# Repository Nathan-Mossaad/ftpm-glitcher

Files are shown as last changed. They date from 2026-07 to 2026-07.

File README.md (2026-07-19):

# Glitching firmware for the AMD SP

(currently only tested on a A520M-HVS & AMD Ryzen 3600)

# Contents

- [Wiring setup](#wiring-setup)
- [Parameter Determination](#parameter-determination)
- [Docs](#docs)
- [Building](#building)
  - [Pico firmware](#pico-firmware)
  - [Cli tool](#cli-tool)
  - [Helper scripts](#helper-scripts)
- [Tips & Tricks](#tips--tricks)

# Wiring setup

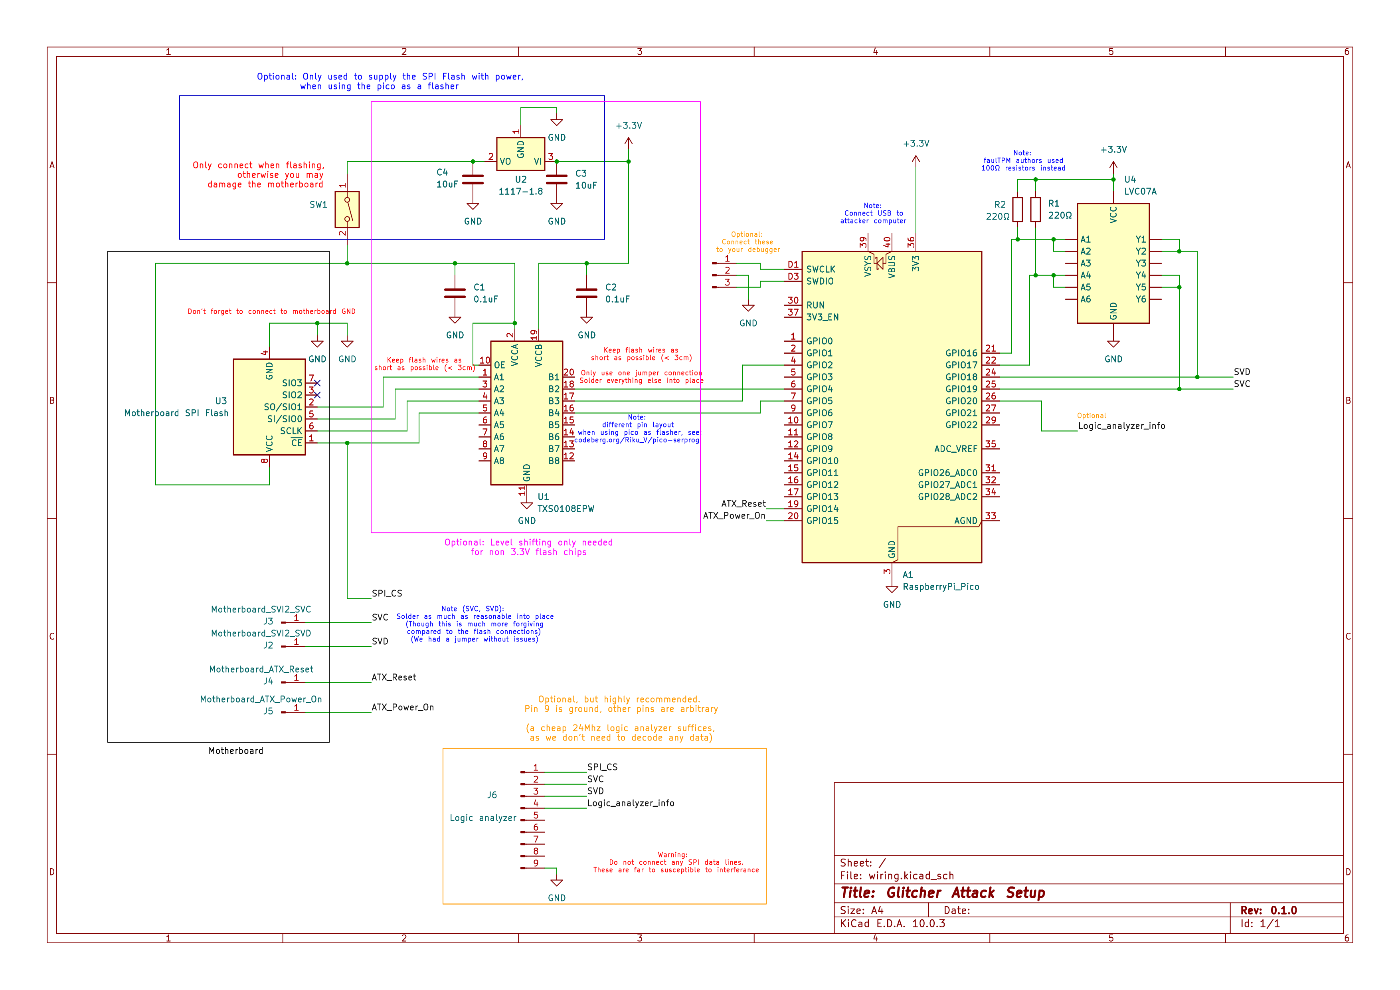
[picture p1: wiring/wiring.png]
wiring png


As pdf: [wiring pdf](./wiring/wiring.pdf)

# Parameter Determination

For the following I'd recommend you read both "faultpm: Exposing amd ftpms' deepest secrets" and "One glitch to rule them all: Fault injection attacks against amd's secure encrypted virtualization"

Use instructions from upstream: [parameter determination by PSPReverse](https://github.com/PSPReverse/amd-sp-glitch/blob/main/attack-code/ParameterDetermination.md)

I would recommend slight some slight variations:

1. Backup the SPI flash (important, as the ftpm secrets are stored there) e.g. using [pico-serprog](https://codeberg.org/Riku_V/pico-serprog)
2. Prepare the modified firmware:

- e.g. [hello world](https://github.com/PSPReverse/amd-sp-glitch/tree/main/payloads/hello-world) (Note it only outputs "H" due to a bug)
- Use [psptool](https://github.com/PSPReverse/PSPTool) to patch the firmware to create a modified SPI flash image

3. Flash the modified firmware
4. Determine the chip select count till ARK validation by using `glitcher count-chip-selects --reboot` (in our case 33)
5. Flash the original firmware
6. Use a few pulses (e.g. 31), use a low wait-duration and increase `dip-duration` till the target fully crashes. The target test range should end slightly before the target crashes. Test using `glitcher attack --chip-select-count <CHIP_SELECT_COUNT> --wait-duration-ns <WAIT_DURATION_NS> --dip-duration-ns <DIP_DURATION_NS> --spi-byte-count 2`
7. Use the logic analyzer to align the end of the second SVI2 packet injection shortly before the end of the validation window. If you have no logic analyzer, you will have to compensate by increaseing the wait-duration range to definitly hit the ark validation.
8. Refine params by setting the custom ranges in [determine-params](helpers/determine-params.py) and run. Now use the resulting values with [duration_test_plot](https://github.com/Nathan-Mossaad/amd-sp-glitch/blob/5e63abd1f0da41acaa2ef0fc65212f0690687d37/attack-code/duration_test_plot.py) to determine a smaller range, in accordance with "One glitch".
9. Flash the modified firmware
10. Start glitching using [extract-data](./helpers/extract-data.py) (see section [Helper scripts](#helper-scripts) for how to use [monitor.sh](./helpers/monitor.sh))

# Docs

Mostly missing, refer to `--help` of `glitcher` for now.

# Building

> [!NOTE]
> This project is only intended for use on Linux.

Install rustup & cargo:

[https://rust-lang.org/tools/install/](https://rust-lang.org/tools/install/)

## Pico firmware

Simple setup:

```bash
# Install pico specific target
rustup target add thumbv6m-none-eabi
# compile the firmware
cd glitcher-controller
cargo build -r
# Generating the uf2
cargo install elf2uf2-rs
elf2uf2-rs target/thumbv6m-none-eabi/release/glitcher-controller target/thumbv6m-none-eabi/release/glitcher-controller.uf2
# Now you can enter bootloader mode on the pico (by holding bootsel while plugging it in) and copy the uf2 file to it.
```

With debugging support:

You can use any [probe-rs](https://probe.rs/docs/getting-started/probe-setup/) compatible debugger, e.g. a PicoProbe (a second pico): [download](https://github.com/raspberrypi/debugprobe/releases) Wiring instructions: [wiring](https://mcuoneclipse.com/2022/09/17/picoprobe-using-the-raspberry-pi-pico-as-debug-probe/)

```bash
# Install pico specific target
rustup target add thumbv6m-none-eabi
# compile the firmware
cd glitcher-controller
# This will build, flash and then attach to the debug output of the pico
cargo run -r
```

## Cli tool

> [!NOTE]
> Make sure your user account belongs to the group that grants access to USB serial devices (for example, `dialout`).

Direct compile and run

```bash
# compile the cli tool
cd glitcher-cli
cargo run -r -- --help
# Check versions on different serial port
cargo run -r -- --port /dev/ttyACM1 check-version
```

Alternatively you may wish to add `glitcher` to your path and use e.g. `glitcher generate-completions zsh` to generate completions for your shell.

## Helper scripts

Managed via [uv](https://docs.astral.sh/uv/getting-started/installation/)

> [!NOTE]
> The main project needs to already run

```bash
# Direcly modify helpers/determine-params.py and helpers/flash-pico.py to your needs
cd helpers
mkdir results

# For param determination
uv run determine-params.py > "results/attack-$(date -Is).txt"
# Monitor the output via:
./monitor.sh
# Additionally get & print spi-tap data
uv run helpers/extract-data.py
```

# Tips & Tricks

Check that pico firmware version matches cli version

```bash
glitcher check-version
```

Almost instant shutdown (by killing power to the CPU :D)

```bash
glitcher disable-telemetry --reboot; glitcher set-vid 252
```

Power on

```bash
glitcher press-power-button --duration-ms 100
```

Count chip selects (mainly usefull with modified firmware for parameter determination)

```bash
glitcher count-chip-selects 3
```

Properly integrate glitcher into zsh with my [zsh setup](https://github.com/Nathan-Mossaad/zshrc)

```bash
cp glitcher-pc/target/release/glitcher ~/.local/bin/glitcher
glitcher generate-completions zsh > ~/.zfunc/_glitcher
# alias glitcher for a different port
echo 'alias glitcher="glitcher --port /dev/ttyACM1"' >> .zshrc
# Reload shell
```

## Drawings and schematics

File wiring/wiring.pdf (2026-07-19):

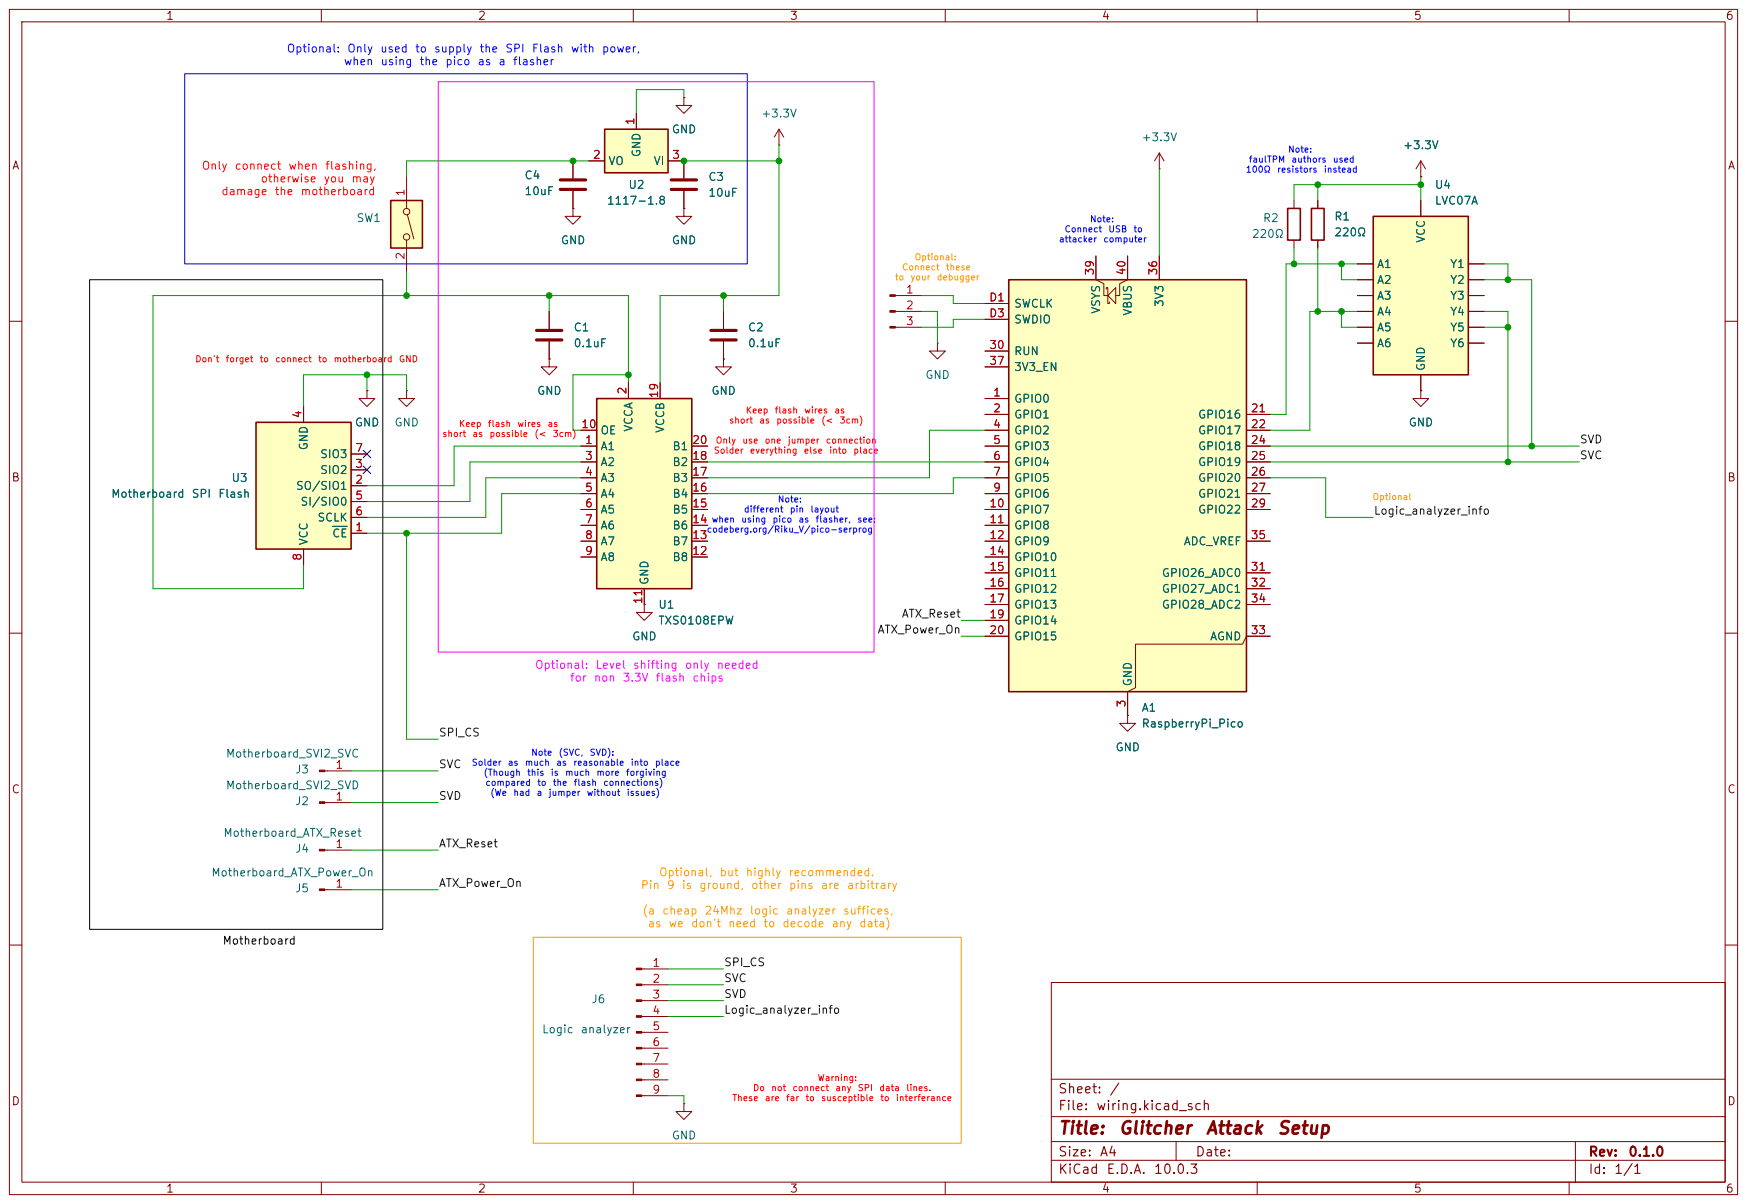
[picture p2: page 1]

8 U3 Motherboard SPI Flash 1 J4 Motherboard_ATX_Reset GND +3.3V C2

Note: Connect USB to

attacker computer Optional: Level shifting only needed

to your debugger Keep flash wires as

(We had a jumper without issues) Keep flash wires as

(a cheap 24Mhz logic analyzer suffices, as we don't need to decode any data) GND U1
TXS0108EPW
GND

for non 3.3V flash chips Motherboard

(Though this is much more forgiving
compared to the flash connections)

Warning: Do not connect any SPI data lines. These are far to susceptible to interferance

Sheet: /
File: wiring.kicad_sch
Title: Glitcher Attack Setup

Size: A4 | Rev: 0.1.0
KiCad E.D.A. 10.0.3 | Id: 1/1

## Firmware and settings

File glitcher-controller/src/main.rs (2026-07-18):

#![no_std]
#![no_main]

use defmt::{error, info, warn};
use embassy_executor::Spawner;
use embassy_rp::{
    bind_interrupts,
    gpio::{Flex, Input, Level, Output, Pull},
    peripherals::PIO0,
    pio,
    watchdog::Watchdog,
};
use embassy_time::Timer;
use glitcher_rpc::{
    ChunkStatus, Controller2HostMessage, FirmwareVersion, Host2ControllerMessage, RpcMessage,
    SPI_TAP_MAX_BYTES, postcard,
};
use static_cell::StaticCell;
use {defmt_rtt as _, panic_probe as _};

mod attack;
mod chip_select;
#[path = "i2c-pio.rs"]
mod i2c_pio;
mod serial;
mod spi_tap;
mod svi2;

bind_interrupts!(struct PioIrqs {
    PIO0_IRQ_0 => pio::InterruptHandler<PIO0>;
});

#[embassy_executor::main]
async fn main(spawner: Spawner) {
    // Warning when running in debug
    if cfg!(debug_assertions) {
        for _ in 0..10 {
            error!("Warning: Running debug build, timings will be off!");
        }
    }

    info!("Starting USB serial!");

    let p = embassy_rp::init(Default::default());

    let mut class = serial::init(spawner, p.USB);
    let mut watchdog = Watchdog::new(p.WATCHDOG);

    // Retain the peripherals and lend short-lived reborrows to either the
    // chip-select counter or the SPI tap.
    let mut spi0 = p.SPI0;
    let mut spi_slave_clk = p.PIN_2;
    let mut spi_slave_miso = p.PIN_4;
    let mut spi_slave_cs_pin = p.PIN_5;
    let mut spi_tx_dma = p.DMA_CH2;
    let mut spi_rx_dma = p.DMA_CH3;
    static SPI_CAPTURE: StaticCell<[u8; SPI_TAP_MAX_BYTES]> = StaticCell::new();
    let capture = SPI_CAPTURE.init([0; SPI_TAP_MAX_BYTES]);

    // PIO I2C: SDA = GPIO16, SCL = GPIO17.
    let pio::Pio {
        mut common, sm0, ..
    } = pio::Pio::new(p.PIO0, PioIrqs);
    let mut i2c = i2c_pio::I2cPio::new(&mut common, sm0, p.PIN_16, p.PIN_17, 2_000_000);

    let mut svd_in = Input::new(p.PIN_18, Pull::None);
    let mut svc_in = Input::new(p.PIN_19, Pull::None);
    let mut logic_analyzer_trigger = Output::new(p.PIN_20, Level::Low);
    let mut target_reboot_pin = Flex::new(p.PIN_15);
    target_reboot_pin.set_pull(Pull::None);
    target_reboot_pin.set_as_input();
    let mut power_button_pin = Flex::new(p.PIN_14);
    power_button_pin.set_pull(Pull::None);
    power_button_pin.set_as_input();

    loop {
        class.wait_connection().await;
        info!("Connected");

        let mut buf = [0; 64];
        loop {
            // Recieve
            let Ok(n) = class
                .read_packet(&mut buf)
                .await
                .map_err(serial::Disconnected::from)
            else {
                break;
            };

            // Handle message.
            let request =
                match postcard::from_bytes::<RpcMessage<Host2ControllerMessage>>(&buf[..n]) {
                    Ok(request) => request,
                    Err(error) => {
                        warn!("Unknown incoming message: {}", error);
                        continue;
                    }
                };

            let mut reboot_requested = false;
            info!("Received: {:?}", request.message);
            let message = match request.message {
                Host2ControllerMessage::Ping => Controller2HostMessage::Pong,
                Host2ControllerMessage::GetVersion => {
                    Controller2HostMessage::Version(firmware_version())
                }
                Host2ControllerMessage::Reboot => {
                    reboot_requested = true;
                    Controller2HostMessage::Rebooting
                }
                Host2ControllerMessage::RebootTarget => {
                    attack::reboot_target(&mut target_reboot_pin).await;
                    Controller2HostMessage::TargetRebooted
                }
                Host2ControllerMessage::PressPowerButton { duration_ms } => {
                    attack::press_power_button(&mut power_button_pin, duration_ms).await;
                    Controller2HostMessage::PowerButtonPressed
                }
                Host2ControllerMessage::GlitchAttack {
                    spi_byte_count,
                    vid,
                    chip_select_count,
                    wait_duration_ns,
                    dip_duration_ns,
                } => match attack::single_attack(
                    &mut target_reboot_pin,
                    &mut svd_in,
                    &mut svc_in,
                    &mut logic_analyzer_trigger,
                    &mut i2c,
                    &mut spi_slave_cs_pin,
                    &mut spi0,
                    &mut spi_slave_clk,
                    &mut spi_slave_miso,
                    &mut spi_tx_dma,
                    &mut spi_rx_dma,
                    capture,
                    spi_byte_count,
                    chip_select_count,
                    vid,
                    wait_duration_ns,
                    dip_duration_ns,
                )
                .await
                {
                    Ok(result) => match write_spi_tap_capture(
                        &mut class, request.id, capture, result, &mut buf,
                    )
                    .await
                    {
                        Ok(()) => continue,
                        Err(serial::ChunkWriteError::Disconnected) => break,
                        Err(serial::ChunkWriteError::Serialize(error)) => {
                            warn!("Failed to serialize chunked response: {}", error);
                            continue;
                        }
                    },
                    Err(message) => message,
                },
                Host2ControllerMessage::CountChipSelects { timeout_s, reboot } => {
                    if reboot {
                        attack::reboot_target(&mut target_reboot_pin).await;
                    }
                    Controller2HostMessage::ChipSelectCount(
                        chip_select::count_chip_selects(timeout_s, &mut spi_slave_cs_pin).await,
                    )
                }
                Host2ControllerMessage::TapSpi {
                    byte_count,
                    timeout_s,
                    reboot,
                } => {
                    if reboot {
                        attack::reboot_target(&mut target_reboot_pin).await;
                    }
                    let result = spi_tap::tap_spi(
                        &mut spi0,
                        &mut spi_slave_clk,
                        &mut spi_slave_miso,
                        &mut spi_slave_cs_pin,
                        &mut spi_tx_dma,
                        &mut spi_rx_dma,
                        capture,
                        byte_count,
                        timeout_s,
                    )
                    .await;

                    match result {
                        Ok(result) => match write_spi_tap_capture(
                            &mut class, request.id, capture, result, &mut buf,
                        )
                        .await
                        {
                            Ok(()) => continue,
                            Err(serial::ChunkWriteError::Disconnected) => break,
                            Err(serial::ChunkWriteError::Serialize(error)) => {
                                warn!("Failed to serialize chunked response: {}", error);
                                continue;
                            }
                        },
                        Err(error) => Controller2HostMessage::SpiTapError(error),
                    }
                }
                Host2ControllerMessage::SetVid { vid } => {
                    info!("Setting SVI2 VID to {:?}", vid);
                    svi2::set_vid(&mut i2c, vid);
                    Controller2HostMessage::VidSet
                }
                Host2ControllerMessage::DisableTelemetry { timeout_ms, reboot } => {
                    if reboot {
                        attack::reboot_target_with_trigger(
                            &mut target_reboot_pin,
                            &mut logic_analyzer_trigger,
                        )
                        .await;
                    }
                    let message = attack::wait_boot_and_disable_telemetry(
                        timeout_ms,
                        &mut svd_in,
                        &mut svc_in,
                        &mut logic_analyzer_trigger,
                        &mut i2c,
                    )
                    .await;
                    message
                }
            };
            let response = RpcMessage {
                id: request.id,
                message,
            };
            info!("Sending: {:?}", response);

            // Serialize response
            let response_bytes = match postcard::to_slice_cobs(&response, &mut buf) {
                Ok(bytes) => bytes,
                Err(error) => {
                    warn!("Failed to serialize response: {}", error);
                    continue;
                }
            };

            // Send response
            if class
                .write_packet(response_bytes)
                .await
                .map_err(serial::Disconnected::from)
                .is_err()
            {
                break;
            }

            if reboot_requested {
                // Give the USB response time to reach the host before reset.
                Timer::after_millis(100).await;
                watchdog.trigger_reset();
            }
        }

        info!("Disconnected");
    }
}

async fn write_spi_tap_capture(
    class: &mut serial::UsbSerial,
    request_id: u32,
    capture: &[u8; SPI_TAP_MAX_BYTES],
    result: spi_tap::SpiTapResult,
    buffer: &mut [u8; 64],
) -> Result<(), serial::ChunkWriteError> {
    let status = if result.timed_out {
        ChunkStatus::TimedOut
    } else {
        ChunkStatus::Complete
    };
    serial::write_chunked(
        class,
        request_id,
        &capture[..result.byte_count],
        status,
        buffer,
    )
    .await
}

fn firmware_version() -> FirmwareVersion {
    FirmwareVersion {
        major: env!("CARGO_PKG_VERSION_MAJOR").parse().unwrap(),
        minor: env!("CARGO_PKG_VERSION_MINOR").parse().unwrap(),
        patch: env!("CARGO_PKG_VERSION_PATCH").parse().unwrap(),
    }
}

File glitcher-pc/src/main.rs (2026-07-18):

use anyhow::{Result, bail};
use clap::{CommandFactory, Parser};
use clap_complete::generate;
use glitcher_rpc::{Controller2HostMessage, FirmwareVersion, Host2ControllerMessage};
use tracing::info;
use tracing_subscriber::EnvFilter;

mod cli;
mod console;

use cli::{Cli, Command};

fn main() -> Result<()> {
    let cli = Cli::parse();

    let filter = EnvFilter::try_from_env("RUST_LOG").unwrap_or_else(|_| EnvFilter::new("info"));
    tracing_subscriber::fmt().with_env_filter(filter).init();

    match cli.command {
        Command::Ping => {
            let ping = Host2ControllerMessage::Ping;
            info!(port = %cli.port.display(), message = ?ping, "Sending message");
            console::send(&cli.port, &ping)?;
            println!("Pong")
        }
        Command::CheckVersion => {
            let desktop_version = desktop_version();
            let response = console::send(&cli.port, &Host2ControllerMessage::GetVersion)?;
            let Controller2HostMessage::Version(firmware_version) = response else {
                bail!("Pico returned an unexpected response to a version request");
            };

            println!("Desktop application version: {desktop_version}");
            println!("Pico firmware version: {firmware_version}");

            if desktop_version != firmware_version {
                eprintln!("\x1b[31mFAIL: desktop and Pico firmware versions do not match\x1b[0m");
                bail!("version mismatch");
            }
        }
        Command::Reboot => {
            let response = console::send(&cli.port, &Host2ControllerMessage::Reboot)?;
            if !matches!(response, Controller2HostMessage::Rebooting) {
                bail!("Pico returned an unexpected response to a reboot request");
            }
            println!("Pico is rebooting");
        }
        Command::RebootTarget => {
            let response = console::send(&cli.port, &Host2ControllerMessage::RebootTarget)?;
            if !matches!(response, Controller2HostMessage::TargetRebooted) {
                bail!("Pico returned an unexpected response to a target reboot request");
            }
            println!("Target reboot pulse sent");
        }
        Command::PressPowerButton { duration_ms } => {
            let response = console::send(
                &cli.port,
                &Host2ControllerMessage::PressPowerButton { duration_ms },
            )?;
            if !matches!(response, Controller2HostMessage::PowerButtonPressed) {
                bail!("Pico returned an unexpected response to a power-button press request");
            }
            println!("Target power button held for {duration_ms} ms");
        }
        Command::CountChipSelects { timeout_s, reboot } => {
            let response = console::send(
                &cli.port,
                &Host2ControllerMessage::CountChipSelects { timeout_s, reboot },
            )?;
            let Controller2HostMessage::ChipSelectCount(count) = response else {
                bail!("Pico returned an unexpected response to a chip-select count request");
            };

            println!("Chip-select falling edges: {count}");
        }
        Command::TapSpi {
            byte_count,
            timeout_s,
            reboot,
        } => {
            let capture = console::tap_spi(&cli.port, byte_count, timeout_s, reboot)?;
            if capture.timed_out {
                eprintln!("SPI tap timed out after {timeout_s} seconds; returning partial capture");
            }
            println!("SPI RX: {:02x?}", capture.data);
            if capture.timed_out {
                bail!("SPI tap timed out after {timeout_s} seconds; Partial capture!");
            }
        }
        Command::SetVid { vid } => {
            let response = console::send(&cli.port, &Host2ControllerMessage::SetVid { vid })?;
            match response {
                Controller2HostMessage::VidSet => {
                    if let Some(vid) = vid {
                        println!("Applied VID {vid} to VSoc and VCore");
                    } else {
                        println!("Applied the default SVI2 VSoc and VCore VIDs");
                    }
                }
                Controller2HostMessage::Svi2Error(error) => {
                    bail!("SVI2 voltage command failed: {error}");
                }
                _ => bail!("Pico returned an unexpected response to an SVI2 voltage request"),
            }
        }
        Command::DisableTelemetry { timeout_ms, reboot } => {
            let response = console::send(
                &cli.port,
                &Host2ControllerMessage::DisableTelemetry { timeout_ms, reboot },
            )?;
            match response {
                Controller2HostMessage::TelemetryDisabled => {
                    if reboot {
                        println!(
                            "SVI2 telemetry disabled and target rebooted after GPIO18 went high"
                        );
                    } else {
                        println!("SVI2 telemetry disabled after GPIO18 went high");
                    }
                }
                Controller2HostMessage::TelemetryTimedOut => {
                    bail!("GPIO18 did not become high within {timeout_ms} seconds");
                }
                Controller2HostMessage::Svi2Error(error) => {
                    bail!("SVI2 telemetry command failed: {error}");
                }
                _ => bail!("Pico returned an unexpected response to the telemetry request"),
            }
        }
        Command::Attack {
            spi_byte_count,
            vid,
            chip_select_count,
            wait_duration_ns,
            dip_duration_ns,
        } => {
            let capture = console::glitch_attack(
                &cli.port,
                spi_byte_count,
                vid,
                chip_select_count,
                wait_duration_ns,
                dip_duration_ns,
            )?;
            println!("Glitch attack succeeded");
            println!("SPI RX: {:02x?}", capture.data);
            if capture.timed_out {
                bail!("attack SPI tap timed out; returning partial capture");
            }
        }
        Command::GenerateCompletions { shell } => {
            generate(
                shell,
                &mut Cli::command(),
                "glitcher",
                &mut std::io::stdout(),
            );
        }
    }

    Ok(())
}

fn desktop_version() -> FirmwareVersion {
    FirmwareVersion {
        major: env!("CARGO_PKG_VERSION_MAJOR").parse().unwrap(),
        minor: env!("CARGO_PKG_VERSION_MINOR").parse().unwrap(),
        patch: env!("CARGO_PKG_VERSION_PATCH").parse().unwrap(),
    }
}

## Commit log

2026-07-15 Added request_id to filter old messages, new reboot command, new chipselect counter
    [cli.rs, console.rs, lib.rs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]
2026-07-15 Proof of concept 32byte SPI tap
2026-07-15 Expanded SPI Tap length with chunked protocol extensions
2026-07-17 Seemingly working i2c via pio ignoring Nacks
2026-07-17 Added timeout to telemetry & fixed reliable trigger
    [cli.rs, lib.rs, main.rs]
2026-07-17 Add reboot command by pulling GP15 low
    [cli.rs, lib.rs, main.rs]
2026-07-17 Added power button behavior
2026-07-17 Added reboot option to tap-spi
    [cli.rs, console.rs, lib.rs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]
2026-07-17 Added reboot option to count chip selects
    [cli.rs, lib.rs, main.rs]
2026-07-17 Added empty glitch attack. Refactor disable_telemetry/wait_boot_and_disable_telemetry
    [attack.rs, cli.rs, lib.rs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]
2026-07-19 Added wiring schematic
    [wiring.kicad_sch]
2026-07-19 Fixed: Missing caps in schematic
    [wiring.kicad_sch]
2026-07-20 Revert "Fix: outstanding warnings"
    This reverts commit 127066c26f6f2f5ceb5d845c416cf00f9040ac25.
    [attack.rs]
2026-07-20 Revert to known working state
    This reverts commit bc6a18f38cac9ce8fbe2b57e987a646df6fd1d27.
    [attack.rs, cli.rs, lib.rs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]
